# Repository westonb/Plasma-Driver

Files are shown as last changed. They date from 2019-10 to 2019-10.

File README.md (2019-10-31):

# Plasma-Driver
A 40W 40.68MHz Class E RF amplifier using a MRF101AN LDMOS Device. The amplifer accepts a 40.68MHz square wave logic level input. A 5V power supply is required for the driver and a DC input of 38V is required to acheive a 40W output. 

## PCB
The PCB directory contains the kicad PCB files for the class E design and for a linear amplifier based on the 40.68MHz refrence design provided in the MRF101AN datasheet

## Schematic 
The schematics directory contains a PDF schematic of the design 

## Simulation 
The simulation directory contains a LTSpice simulation of the amplifier using a model of the MRF101AN derived from the datasheet and in-circuit testing 

## Picture 
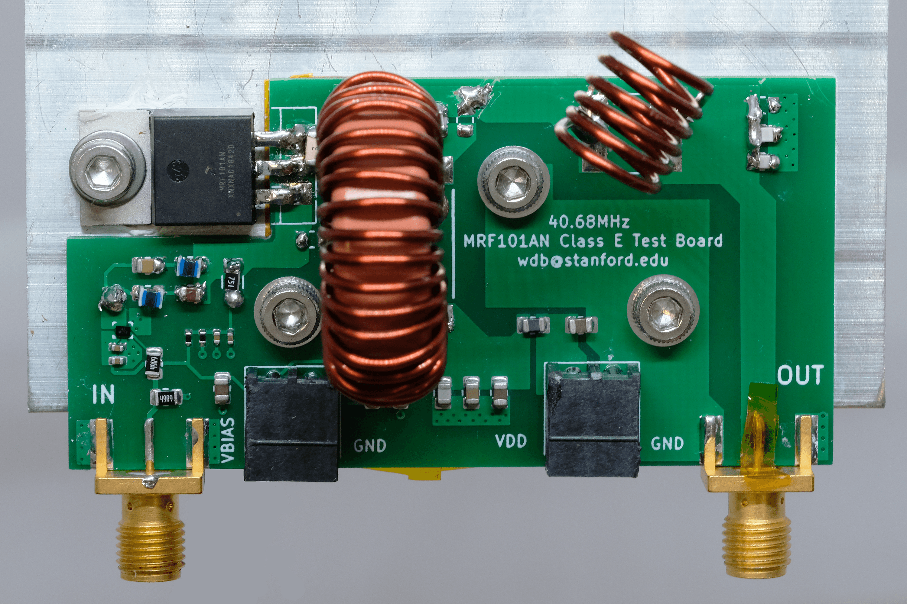
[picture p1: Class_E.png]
Image of Prototype


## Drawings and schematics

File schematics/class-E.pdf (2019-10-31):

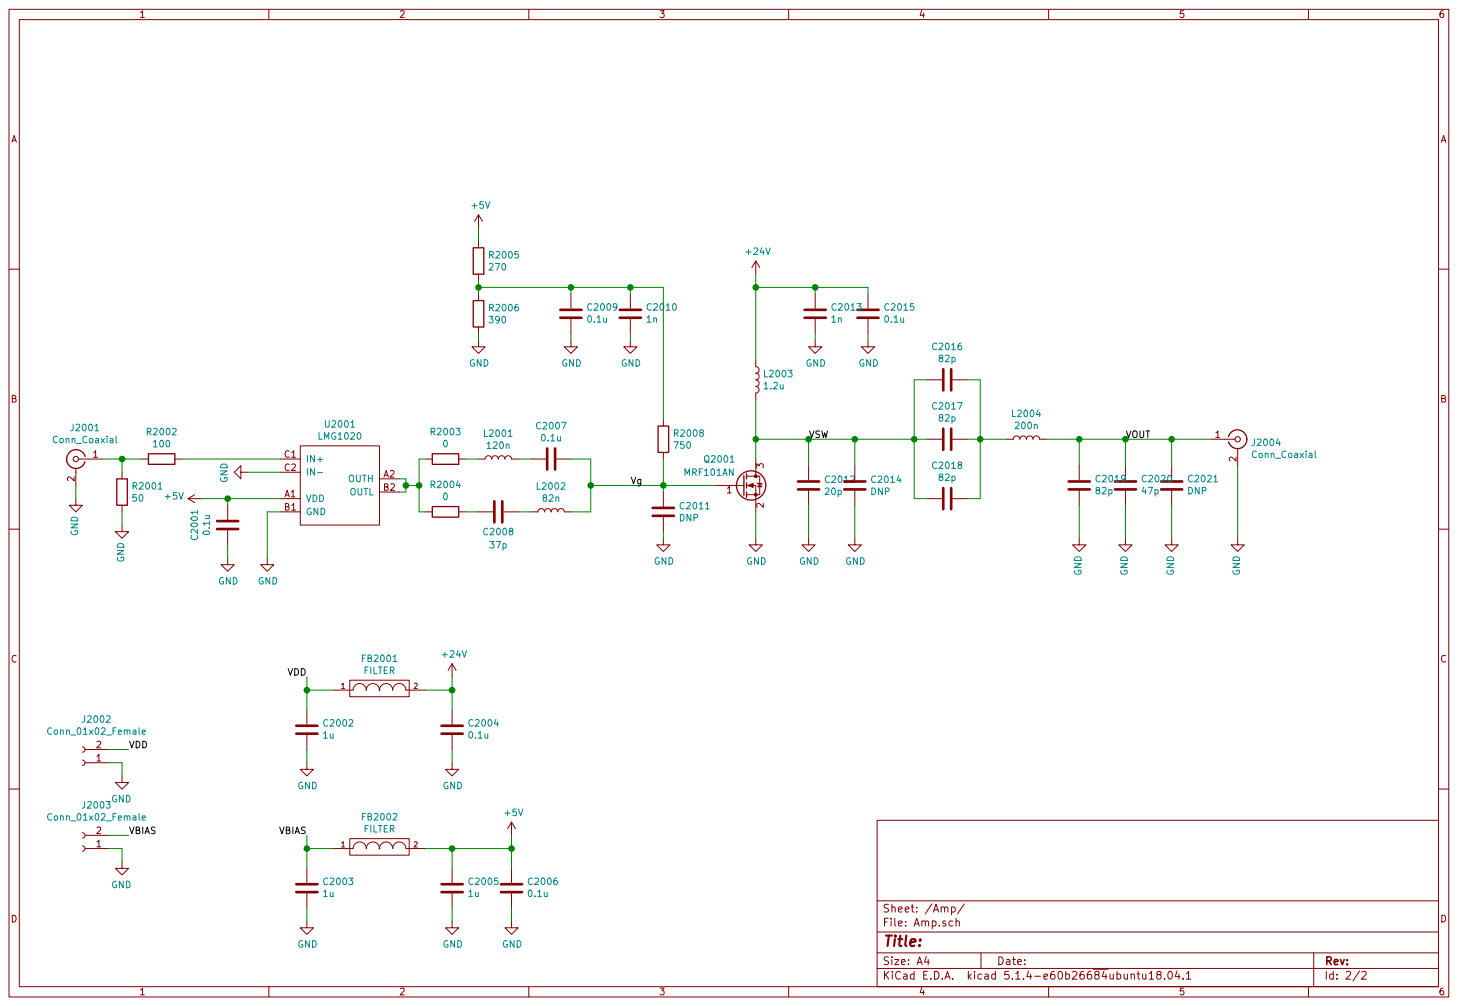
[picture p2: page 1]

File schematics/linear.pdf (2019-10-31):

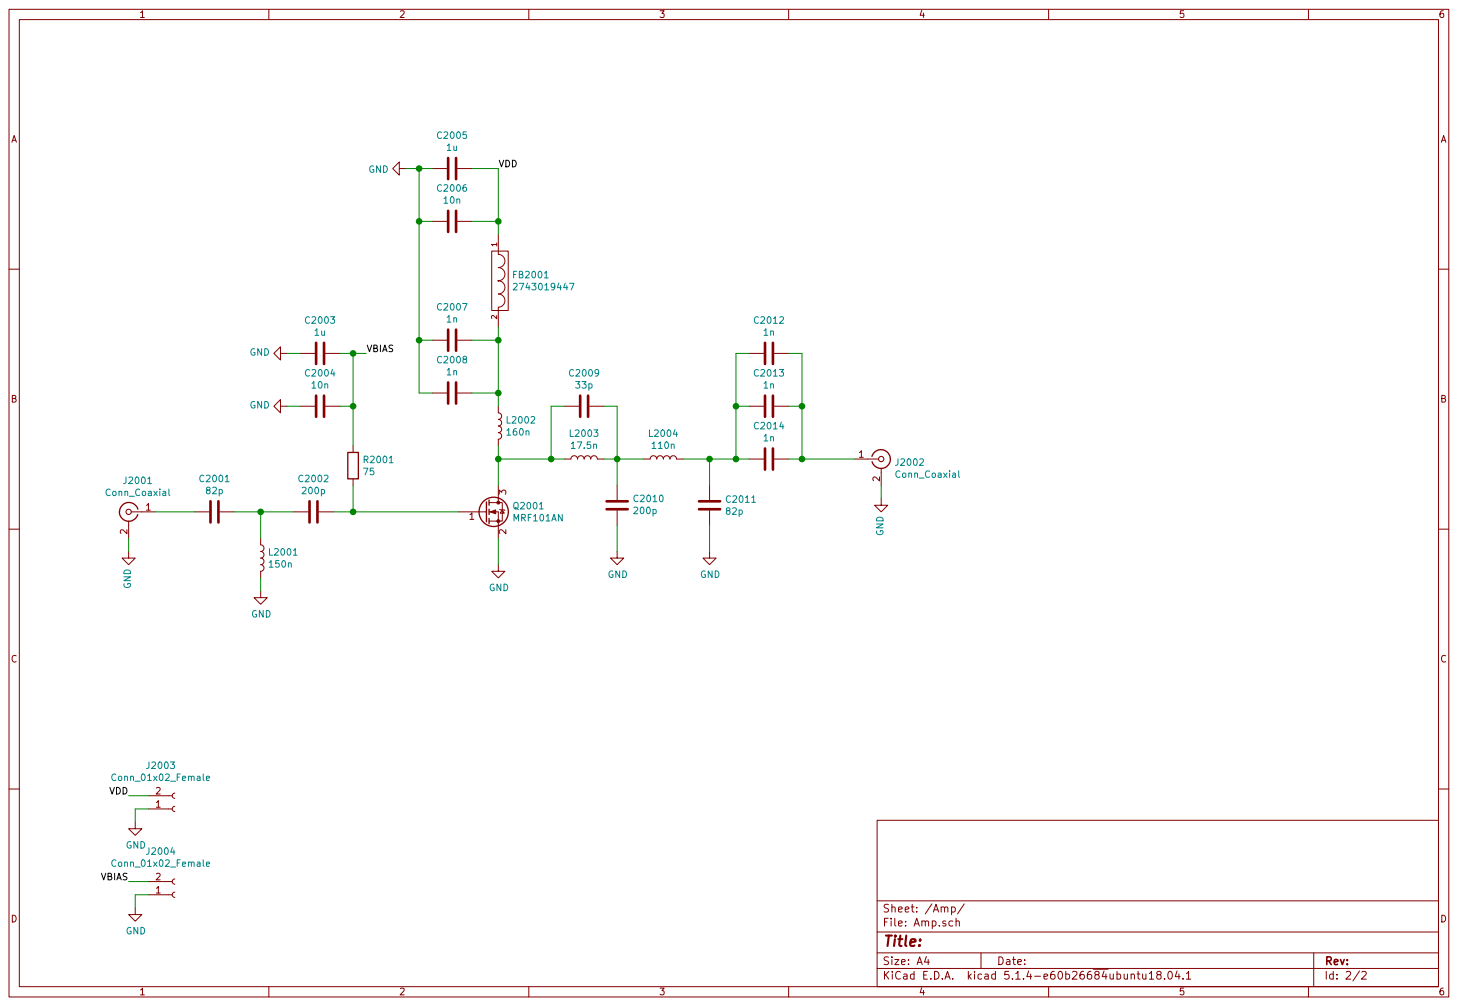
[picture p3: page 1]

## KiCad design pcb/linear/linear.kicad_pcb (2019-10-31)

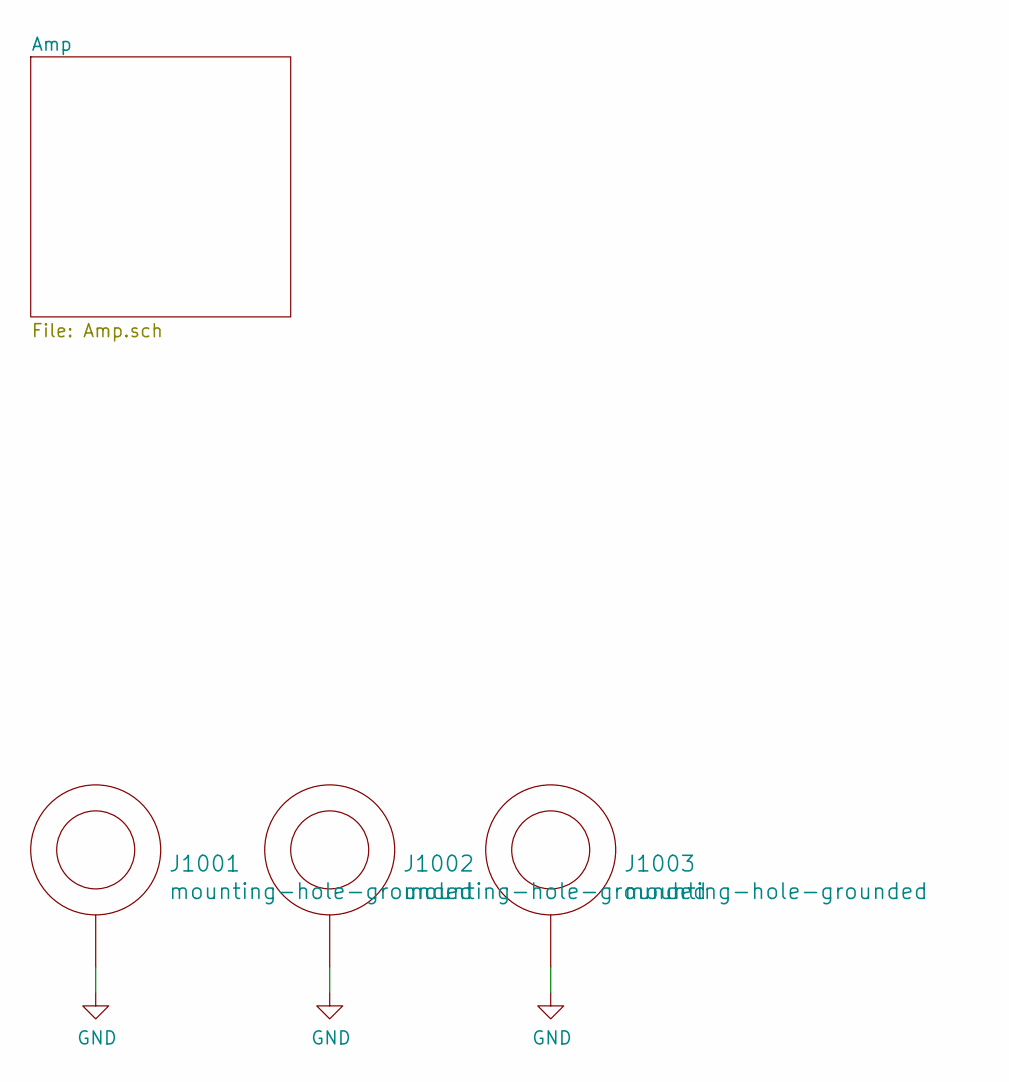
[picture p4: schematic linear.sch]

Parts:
J1001, J1002, J1003: mounting-hole-grounded; M3-tight-fit-socket-head

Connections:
GND: J1001.1, J1002.1, J1003.1; also elsewhere on the board

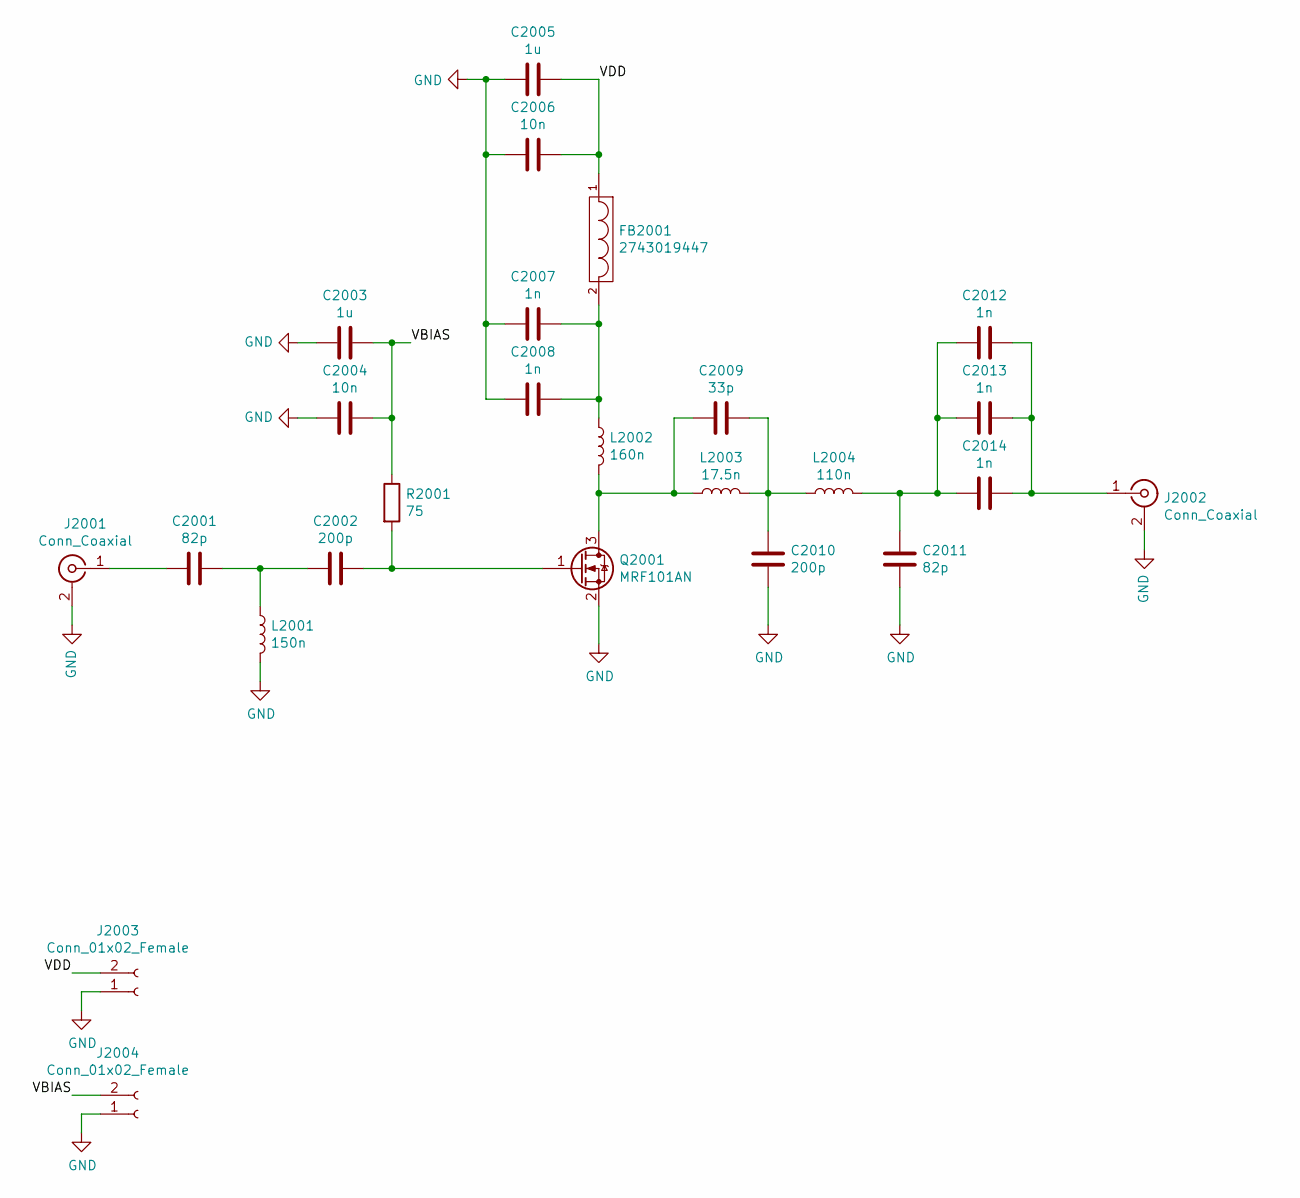
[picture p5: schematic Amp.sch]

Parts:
C2001, C2011: 82p; C_0805_2012Metric
C2002, C2010: 200p; C_0805_2012Metric
C2003, C2005: 1u; C_0805_2012Metric
C2004, C2006: 10n; C_0805_2012Metric
C2007, C2008, C2012, C2013, C2014: 1n; C_0805_2012Metric
C2009: 33p; C_0805_2012Metric
FB2001: 2743019447
J2001, J2002: Conn_Coaxial; SMA-Edge
J2003, J2004: Conn_01x02_Female; Terminal-block-plug_2x1_3.5mm-pitch
L2001: 150n; L_0805_2012Metric
L2002: 160n; 2222SQ-161
L2003: 17.5n; GA3095-AL
L2004: 110n; 2222SQ-111
Q2001: MRF101AN; TO-220-3_Vertical
R2001: 75; R_0805_2012Metric

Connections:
/Amp/VBIAS: C2003.2, C2004.2, J2004.2, R2001.1
/Amp/VDD: C2005.1, C2006.1, FB2001.1, J2003.2
GND: C2003.1, C2004.1, C2005.2, C2006.2, C2007.2, C2008.2, C2010.1, C2011.2, J2001.2 (Ext), J2002.2 (Ext), J2003.1, J2004.1, L2001.2, Q2001.2 (S); also elsewhere on the board
unnamed: C2001.1, C2002.2, L2001.1
unnamed: C2001.2, J2001.1 (In)
unnamed: C2002.1, Q2001.1 (G), R2001.2
unnamed: C2007.1, C2008.1, FB2001.2, L2002.1
unnamed: C2009.1, C2010.2, L2003.2, L2004.1
unnamed: C2009.2, L2002.2, L2003.1, Q2001.3 (D)
unnamed: C2011.1, C2012.2, C2013.2, C2014.2, L2004.2
unnamed: C2012.1, C2013.1, C2014.1, J2002.1 (In)

Board: 2 copper layers, 28 parts (0 on the bottom side), 11 nets, no tracks yet.

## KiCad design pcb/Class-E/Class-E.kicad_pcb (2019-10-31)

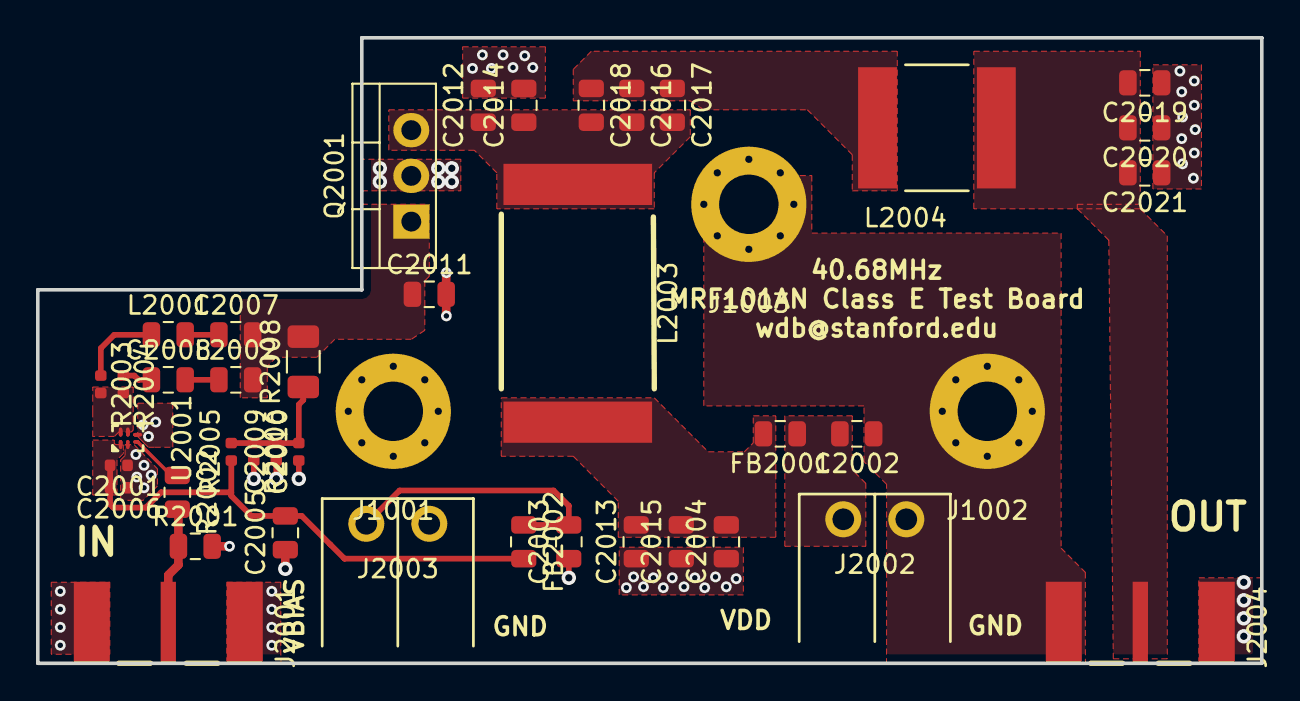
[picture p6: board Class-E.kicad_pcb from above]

Board: 2 copper layers, 68.0 x 34.8 mm, 43 parts (0 on the bottom side), 17 nets.

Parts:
C2001, C2006, C2009: 0.1u; C_0402_1005Metric
C2002, C2003, C2005: 1u; C_0805_2012Metric
C2004, C2007, C2015: 0.1u; C_0805_2012Metric
C2008, C2011: DNP; C_0805_2012Metric
C2010: 1n; C_0402_1005Metric
C2012, C2018, C2021: 47p; C_0805_2012Metric
C2013: 1n; C_0805_2012Metric
C2014: 56p; C_0805_2012Metric
C2016, C2017: 150p; C_0805_2012Metric
C2019, C2020: 82p; C_0805_2012Metric
FB2001, FB2002: FILTER; L_0805_2012Metric
J1001, J1002, J1003: mounting-hole-grounded; M3-tight-fit-socket-head
J2001, J2004: Conn_Coaxial; SMA-Edge
J2002, J2003: Conn_01x02_Female; Terminal-block-plug_2x1_3.5mm-pitch
L2001: 100n; L_0805_2012Metric
L2002: DNP; L_0805_2012Metric
L2003: 500n; 2929SQ-501
L2004: 160n; 2222SQ-161
Q2001: MRF101AN; TO-220-3_Vertical
R2001: 50; R_0805_2012Metric
R2002: 100; R_0805_2012Metric
R2003: 1; R_0402_1005Metric
R2004: DNP; R_0402_1005Metric
R2005, R2006: 270; R_0402_1005Metric
R2008: 75; R_1206_3216Metric
U2001: LMG1020; WLCSP-6

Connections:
+5V: C2001.2, C2005.2, C2006.2, FB2002.2, R2005.1, U2001.A1
+24V: C2004.2, C2013.2, C2015.2, FB2001.2, L2003.1
/Amp/VBIAS: C2003.2, FB2002.1, J2003.2
/Amp/VDD: C2002.2, FB2001.1, J2002.2
/Amp/VOUT: C2019.2, C2020.2, C2021.2, J2004.1, L2004.2
/Amp/VSW: C2012.1, C2014.1, C2016.2, C2017.2, C2018.2, L2003.2, Q2001.3
/Amp/Vg: C2007.2, C2011.1, L2002.2, Q2001.1, R2008.2
GND: C2001.1, C2002.1, C2003.1, C2004.1, C2005.1, C2006.1, C2009.1, C2010.1, C2011.2, C2012.2, C2013.1, C2014.2, C2015.1, C2019.1, C2020.1, C2021.1, J1001.1, J1002.1, J1003.1, J2001.2, J2002.1, J2003.1, J2004.2, Q2001.2, R2001.2, R2006.2, U2001.B1, U2001.C2
unnamed: C2007.1, L2001.2
unnamed: C2008.1, R2004.1
unnamed: C2008.2, L2002.1
unnamed: C2009.2, C2010.2, R2005.2, R2006.1, R2008.1
unnamed: C2016.1, C2017.1, C2018.1, L2004.1
unnamed: J2001.1, R2001.1, R2002.2
unnamed: L2001.1, R2003.1
unnamed: R2002.1, U2001.C1
unnamed: R2003.2, R2004.2, U2001.A2, U2001.B2

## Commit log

2019-10-31 Moved files to project repo
    [Amp.sch, Class-E.kicad_pcb, Class-E.sch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]
2019-10-31 added prototype picture
